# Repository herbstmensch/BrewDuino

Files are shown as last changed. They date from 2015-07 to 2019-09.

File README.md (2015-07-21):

# BrewDuino
BrewDuino ist eine einfache Brau-Steuerungs-Software für Hobbybrauer.

## Inhalt
- [Funktionen](#funktionen)
	- [Maischen](#maischen)
	- [Kochen](#kochen)
	- [Heizen](#heizen)
	- [Timer](#timer)
	- [Einstellungen (noch nicht implementiert)](#einstellungen)
- [Hardware](#hardware)
	- [Schaltplan](#schaltplan)
	- [Board](#board)
	- [Bauteile](#bauteile)
	- [Anschlüsse](#anschlüsse)
- [Bilder](#bilder)
	- [Board unbestückt](#board-unbestückt)
	- [Board bestückt](#boars-bestückt)

### Funktionen

#### Maischen
* Definition und Ausführung des Kompletten Maischeplans.
* Optische und akustische Warung bei Erreichen der Einmaischtemperatur
* Unterbrechung des Maischeplans, bis eingemaischt wurde
* Optische und akustische Warung bei Erreichen der Abmaischtemperatur

#### Kochen
* Freie Definition der Hopfengaben
* Sekundengenaue Messung der Kochzeit
* Optische und akustische Warung für Hopfengaben
* Optische und akustische Warung nach Ablauf der Kochzeit

#### Heizen
* Heizt auf eine eingegebene Temperatur
* Hält diese Temperatur dauerhaft

#### Timer
* Countdown einer eingegebenen Zeit
* Optische und akustische Warung bei Ablauf der Zeit

#### Einstellungen (noch nicht implementiert)
* Anpassung aller Betriebsparameter:
  * Ein-Ausschalt Temperaturoffset
  * Intervall der Temperaturmessungen
  * Ein- / Ausschalten der akustischen Warnungen
  * Ein- / Ausschalten der optischen Warnungen

### Hardware
* Prozessor: ATmega 328P, Arduino-Bootloader
* Display: Nokia 5110 Display (PCD8544)
* SainSmart Relaiskarte
* DS18B20 Temperatursensor
* Rotary Encoder mit Button
 
#### Schaltplan
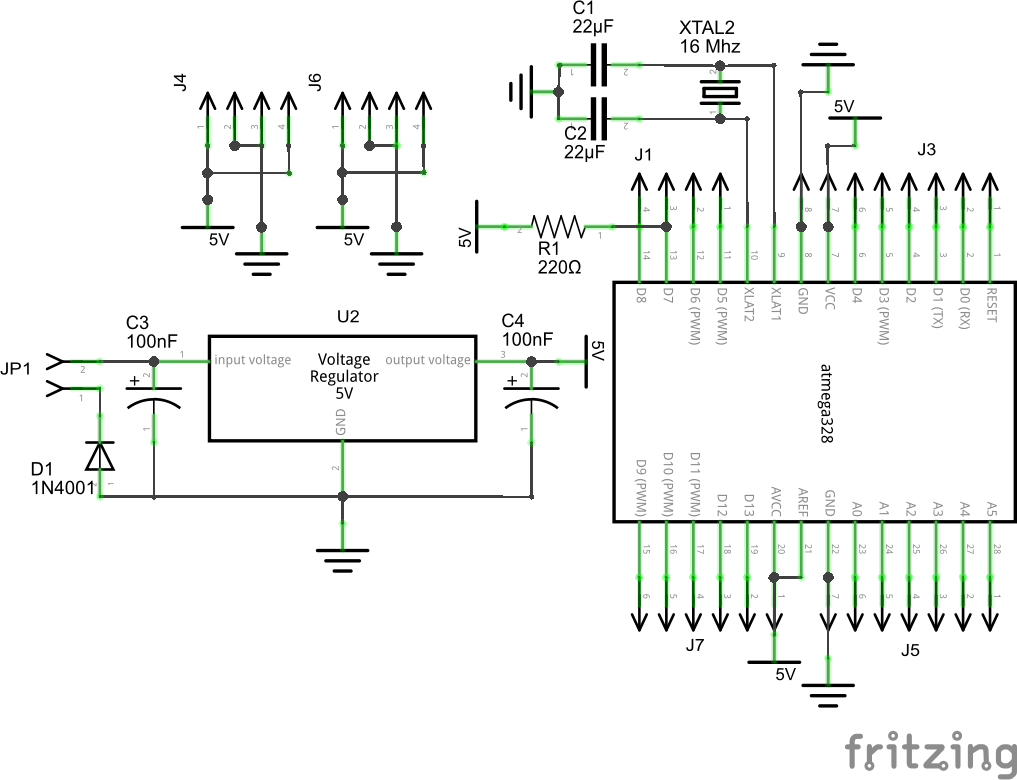
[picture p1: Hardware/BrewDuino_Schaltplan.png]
Schaltplan


#### Board
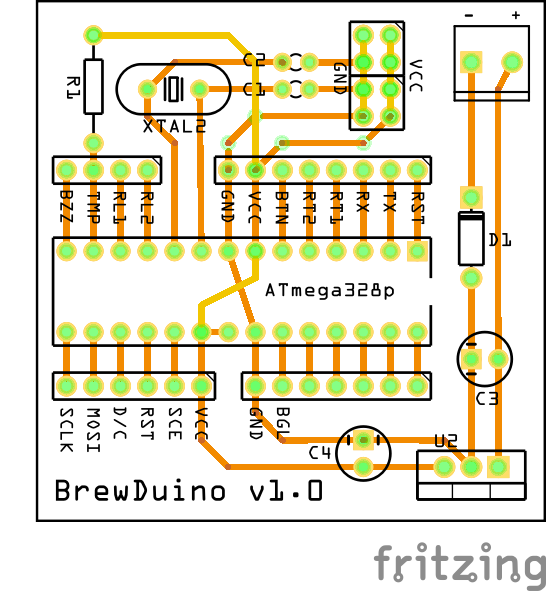
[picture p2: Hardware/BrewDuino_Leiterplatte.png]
PCB


#### Bauteile
Bezeichnung | Bauteil
------------ | -------------
C1 | Kondensator 22 uF
C2 | Kondensator 22 uF
C3 | Kondensator 100 nF
C4 | Kondensator 100 nF
U2 | Spannungsregulator
D1 | Diode
JX | PinHeader
XTAL2 | Quartz 16 Mhz
R1 | Wiederstand 220 Ohm

#### Anschlüsse
Bezeichung | Anschluß
-----------|---------
VCC  | Versorgungsspannung 5V
GND  | MAsse
SCE  | Nokia 5110 Display SCE
RST  | Nokia 5110 Display RST
D/C  | Nokia 5110 Display D/C
MOSI | Nokia 5110 Display MOSI
SCLK | Nokia 5110 Display SCLK
RST  | Reset (Arduino Reset)
TX   | Tranceive (Arduino Serial Programming)
RX   | Receive (Arduino Serial Programming)
RT1  | Rotary Encoder
RT2  | Rotary Encoder
BTN  | Button zur Eingabe
RL1  | Relais 1 (Kocher oder Heizplatte)
RL2  | Relais 2 (Rührwerk)
TMP  | Temperatursensor Data
BZZ  | Summer

### Bilder

#### Board unbestückt
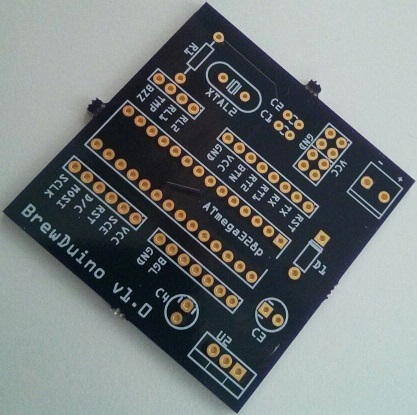
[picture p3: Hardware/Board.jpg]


#### Board bestückt
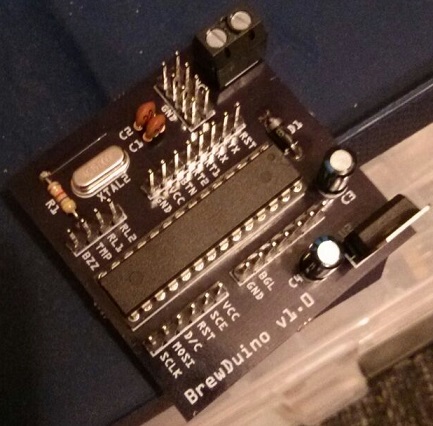
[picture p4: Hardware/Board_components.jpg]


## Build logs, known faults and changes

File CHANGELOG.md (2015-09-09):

# Changelog
## Version 1.1
Released: ---

Bug Fixes:
 - Fixed random program crashes due to String handling

## Version 1.0
Released: 2015-08-12

Changes: first release

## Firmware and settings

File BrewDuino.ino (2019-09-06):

#define CREATOR "rellit"
#define PROG_NAME "BrewDuino"
#define PROG_VERSION "v1.1"
#define COPYRIGHT "(c)2015 - 2019"
#define COPYRIGHT2 "Tim Haller"
#include <LCD5110_Basic.h>
#include <ClickEncoder.h>
#include <TimerOne.h>
#include "FiniteStateMachine.h"
#include <OneWire.h>
#include <DallasTemperature.h>

//Pins benennen
#define PIN_ROTARY_1 2
#define PIN_ROTARY_2 3
#define PIN_ROTARY_BUTTON 4
#define PIN_BG_LIGHT A0
#define PIN_STIRER 5
#define PIN_HEATER 6
#define PIN_THERMOMETER 7
#define PIN_BUZZER 8
#define PIN_LCD_SCLK 9
#define PIN_LCD_MOSI 10
#define PIN_LCD_DC 11
#define PIN_LCD_RST 12
#define PIN_LCD_SCE 13

#define NUMITEMS(arg) ((unsigned int) (sizeof (arg) / sizeof (arg [0])))

//Konfigurationsparameter festlegen
#define TEMP_OFFSET 1
#define MIN_TEMP -999
#define KOCH_TEMP 100
#define TMP_SMOOTH 5
#define MAX_LONG 2147483647L;
#define ENC_HALFSTEP
#define SERIAL J
#define DEBUG 0

//Fehler festlegen
#define ERROR_NO_THERMOMETER 1

int errors = 0, lastErrors = 0;

//Display einrichten
//Old LCD5110 lcd(8, 9, 10, 11, 12);
LCD5110 lcd(PIN_LCD_SCLK, PIN_LCD_MOSI, PIN_LCD_DC, PIN_LCD_RST, PIN_LCD_SCE);
extern uint8_t SmallFont[];
char lcdBuf[15] = {0, 0, 0, 0, 0, 0, 0, 0, 0, 0, 0, 0, 0, 0, 0}; //Buffer für Konkatenierte Display ausgaben

//Encoder einrichten;
ClickEncoder *encoder;
int16_t encoderValue;

//Temperatursensor DS1820 Initialisierung
OneWire oneWire(PIN_THERMOMETER);
DallasTemperature sensors(&oneWire);
DeviceAddress thermometer;

//Funktions-Prototypen
void initThermometer();
void enterMenu() ;
void leaveMenu();
void enterError();
void enterMaischen();
void leaveMaischen();
void enterKochen() ;
void leaveKochen();
void enterHeizen() ;
void leaveHeizen() ;
void enterTimer() ;
void menu() ;
void menuUp() ;
void menuDown();
void error() ;
void maischen() ;
void kochen() ;
void heizen();
void timer() ;
void readTemperature() ;
void setSollTemp(int t) ;
void checkHeatingStatus(bool force);
void turnOffHeating();
void turnOnHeating();
void turnOffStiring();
void turnOnStiring() ;
void addTemperature(boolean force);
void clrScr(bool clearFirst, bool clearLast);
void printRow(char* text, int pos, int row);
void timerIsr() ;
void forceFirstDisplay();
void alarm() ;
void doAlert() ;
void cancelAlarm() ;
bool buttonClicked();
void checkForErrors();
void doHeizen();
void enterKochzeit() ;
void enterAnzahlHopfengaben() ;
void defineHopfengaben();
void enterDoKochen();
void doKochen() ;
void prepareReachKochTemp();
void reachKochTemp() ;
void prepareKochDauer();
void waitKochDauer() ;
void alertHopfengabe();
void enterEinmaischTemp() ;
void enterAnzahlRasten() ;
void defineRast();
void enterAbmaischTemp() ;
void prepareReachEinmaischTemp();
void reachEinmaischTemp();
void einmaischen();
void reachRastTemp() ;
void prepareRastDauer() ;
void waitRastDauer() ;
void reachAbmaischTemp();
void doTimer();
void prepareDoTimer();
void enterTimerTime();

//Main FSM und States definieren
State stateMenu = State(enterMenu, menu, leaveMenu);
State stateError = State(enterError, error, NULL);
State stateMaischen = State(enterMaischen, maischen, leaveMaischen);
State stateKochen = State(enterKochen, kochen, leaveKochen);
State stateHeizen = State(enterHeizen, heizen, leaveHeizen);
State stateTimer = State(enterTimer, timer, NULL);
//State stateSettings = State(enterSettings, settings, NULL);
FSM fsmMain = FSM(stateMenu);

//Maischen FSM und States definieren
State stateEnterEinmaischTemp = State(forceFirstDisplay, enterEinmaischTemp, NULL);
State stateEnterAnzahlRasten = State(forceFirstDisplay, enterAnzahlRasten, NULL);
State stateDefineRast = State(forceFirstDisplay, defineRast, NULL);
State stateEnterAbmaischTemp = State(forceFirstDisplay, enterAbmaischTemp, NULL);
State stateReachEinmaischTemp = State(prepareReachEinmaischTemp, reachEinmaischTemp, NULL);
State stateEinmaischen = State(einmaischen);
State stateReachRastTemp = State(reachRastTemp);
State stateWaitRastDauer = State(prepareRastDauer, waitRastDauer, NULL);
State stateReachAbmaischTemp = State(NULL, reachAbmaischTemp, NULL);
FSM fsmMaischen = FSM(stateEnterEinmaischTemp);

//Kochen FSM und States definieren
State stateEnterKochzeit = State(forceFirstDisplay, enterKochzeit, NULL);
State stateEnterAnzahlHopfengaben = State(forceFirstDisplay, enterAnzahlHopfengaben, NULL);
State stateDefineHopfengaben = State(forceFirstDisplay, defineHopfengaben, NULL);
State stateDoKochen = State(enterDoKochen, doKochen, NULL);
FSM fsmKochen = FSM(stateEnterKochzeit);

//Timer FSM und States definieren
State stateEnterTimerTime = State(forceFirstDisplay, enterTimerTime, NULL);
State stateDoTimer = State(prepareDoTimer, doTimer, NULL);
FSM fsmTimer = FSM(stateEnterTimerTime);

//Variablen initialisieren

int selectedMenuEntry = 0, menuOffset = 0;
//char* menuEntrys[] = {"Maischen","Kochen","Heizen","Timer","Einstell."};
char* menuEntrys[] = {"Maischen", "Kochen", "Heizen", "Timer"};
float lastTemps[TMP_SMOOTH] = {0, 0, 0, 0, 0};
float tempTotal = 0;
int temp, lastTemp, sollTemp, lastHeatCheckTemp, tmpIndex = 0;

unsigned long lastRest = -1;
unsigned long dauer = 0;
unsigned long storedSystemMillis = 0;
unsigned long lastTempMillis;
unsigned long alertMillis = 0;

bool first = false;
bool isHeating, isStiring = false;

void setup()   {
  //LCD Setup
  lcd.InitLCD();
  lcd.clrScr();
  lcd.setFont(SmallFont);
  printRow(CREATOR, LEFT, 0);
  printRow(PROG_NAME" "PROG_VERSION, LEFT, 16);
  printRow(COPYRIGHT, LEFT, 32);
  printRow(COPYRIGHT2, RIGHT, 40);
  Serial.begin(9600);
  Serial.print("Test");


  pinMode(PIN_BG_LIGHT, OUTPUT);
  pinMode(PIN_HEATER, OUTPUT);
  pinMode(PIN_STIRER, OUTPUT);
  digitalWrite(PIN_BG_LIGHT, LOW);
  digitalWrite(PIN_HEATER, HIGH);
  digitalWrite(PIN_STIRER, HIGH);

  isStiring = false;

  //Encoder und Interrupt Setup
  encoder = new ClickEncoder(PIN_ROTARY_1, PIN_ROTARY_2, PIN_ROTARY_BUTTON, 4);
  encoder->setAccelerationEnabled(false);
  Timer1.initialize(1000);
  Timer1.attachInterrupt(timerIsr);

  //Temperaturen und Heizung initialisieren
  setSollTemp(MIN_TEMP);
  isHeating = false;

  initThermometer();

  checkForErrors();
  delay(2000);
  if (errors > 0) {
    fsmMain.immediateTransitionTo(stateError);
    alarm();
  } else {
    fsmMain.immediateTransitionTo(stateMenu);
  }
}

void loop() {
  fsmMain.update();
  ClickEncoder::Button b = encoder->getButton();
  if (b != ClickEncoder::Open) {
    if ( b == ClickEncoder::Held ) {
      fsmMain.transitionTo(stateMenu);
    }
  }

  readTemperature();
  checkHeatingStatus(false);
  addTemperature(false);

  if (alertMillis != 0)
    doAlert();
}

void initThermometer() {
  sensors.begin();
  sensors.getAddress(thermometer, 0);
  // set the resolution to 9 bit (Each Dallas/Maxim device is capable of several different resolutions)
  sensors.setResolution(thermometer, 9);
  //Init Temp array
  for (int i = 0; i < TMP_SMOOTH; i++) {
    sensors.setWaitForConversion(true);
    sensors.requestTemperatures();
    //Letzte Temperatur dieser Position aus Summe nehmen
    tempTotal -= lastTemps[tmpIndex];
    //Neue Temperatur dieser Position schreiben
    lastTemps[tmpIndex] = sensors.getTempC(thermometer);
    //Neue Temperatur dieser Position zur Summe hinzunehmen und Position erhöhen
    tempTotal += lastTemps[tmpIndex++];

    //Durchschnitt errechnen
    temp = tempTotal / TMP_SMOOTH;
  }

  tmpIndex = 0;
  sensors.setWaitForConversion(false);
  sensors.requestTemperatures();
}

void enterMenu() {
  encoder->setAccelerationEnabled(false);
  //selectedMenuEntry = 0;
  //menuOffset = 0;
  setSollTemp(MIN_TEMP);
  checkHeatingStatus(true);
  clrScr(true, false);
  printRow(PROG_NAME" "PROG_VERSION, CENTER, 0);
  forceFirstDisplay();
}

void leaveMenu() {
  encoder->setAccelerationEnabled(true);
}

void enterError() {
  setSollTemp(MIN_TEMP);
  checkHeatingStatus(true);
  clrScr(true, true);
  printRow("--Fehler--", CENTER, 0);
  forceFirstDisplay();
}

void enterMaischen() {
  encoder->setAccelerationEnabled(true);
  fsmMaischen.immediateTransitionTo(stateEnterEinmaischTemp);
  clrScr(true, false);
  printRow("--Maischen--", CENTER, 0);
}

void leaveMaischen() {
  setSollTemp(MIN_TEMP);
}

void enterKochen() {
  encoder->setAccelerationEnabled(true);
  setSollTemp(KOCH_TEMP);
  checkHeatingStatus(true);
  fsmKochen.immediateTransitionTo(stateEnterKochzeit);
  clrScr(true, false);
  printRow("--Kochen--", CENTER, 0);
}

void leaveKochen() {
  setSollTemp(MIN_TEMP);
}

void enterHeizen() {
  encoder->setAccelerationEnabled(true);
  setSollTemp(temp);
  clrScr(true, false);
  printRow("--Heizen--", CENTER, 0);
  forceFirstDisplay();
}

void leaveHeizen() {
  setSollTemp(MIN_TEMP);
}

void enterTimer() {
  encoder->setAccelerationEnabled(true);
  fsmTimer.immediateTransitionTo(stateEnterTimerTime);
  clrScr(true, false);
  printRow("--Timer--", CENTER, 0);
}

/*void enterSettings(){
  fsmSettings.immediateTransitionTo();
  }*/

void menu() {
  encoderValue = encoder->getValue();

  if (encoderValue != 0 || first) {
    first = false;
    if (encoderValue > 0)
      for (int i = 0; i < encoderValue; i++)
        menuUp();
    if (encoderValue < 0)
      for (int i = encoderValue; i < 0; i++)
        menuDown();

    clrScr(false, false);
    if (selectedMenuEntry == 0 + menuOffset)
      printRow("=>", 10, 16);
    lcd.print(menuEntrys[0 + menuOffset], 25, 16);
    if (selectedMenuEntry == 1 + menuOffset)
      printRow("=>", 10, 24);
    lcd.print(menuEntrys[1 + menuOffset], 25, 24);
  }

  if (buttonClicked()) {
    if (selectedMenuEntry == 0)
      fsmMain.transitionTo(stateMaischen);
    if (selectedMenuEntry == 1)
      fsmMain.transitionTo(stateKochen);
    if (selectedMenuEntry == 2)
      fsmMain.transitionTo(stateHeizen);
    if (selectedMenuEntry == 3)
      fsmMain.transitionTo(stateTimer);
    //if(selectedMenuEntry == 4)
    //fsmMain.transitionTo(stateSettings);
    //alarm();
  }
}

void menuUp() {
  selectedMenuEntry -= 1;
  if (selectedMenuEntry < 0)
    selectedMenuEntry = 0;
  if (selectedMenuEntry < menuOffset)
    menuOffset--;
}

void menuDown() {
  selectedMenuEntry += 1;
  if (selectedMenuEntry > NUMITEMS(menuEntrys) - 1)
    selectedMenuEntry = NUMITEMS(menuEntrys) - 1;
  if (selectedMenuEntry > menuOffset + 1)
    menuOffset += 1;
}

void error() {
  if (lastErrors != errors || first) {

    lastErrors = errors;

    if (errors >= ERROR_NO_THERMOMETER) {
      errors -= ERROR_NO_THERMOMETER;
      lcd.print("Kein Therm.", 0, 16);
    }

  }
}

void maischen() {
  fsmMaischen.update();
}

void kochen() {
  fsmKochen.update();
}

void heizen() {
  doHeizen();
}

void timer() {
  fsmTimer.update();
}
/*void settings(){
  fsmSettings.update();
  }*/

void readTemperature() {

  //Gelesen wir nur alle 2,5 sec.
  if (millis() - lastTempMillis > 2500 && sensors.isConversionAvailable(0)) {
    lastTempMillis = millis();

    //Letzte Temperatur dieser Position aus Summe nehmen
    tempTotal -= lastTemps[tmpIndex];
    //Neue Temperatur dieser Position schreiben
    lastTemps[tmpIndex] = sensors.getTempC(thermometer);
    //Neue Temperatur dieser Position zur Summe hinzunehmen und Position erhöhen
    tempTotal += lastTemps[tmpIndex++];

    //Durchschnitt errechnen
    temp = tempTotal / TMP_SMOOTH;

    //Ggf. Position korrigieren
    if (tmpIndex >= TMP_SMOOTH)
      tmpIndex = 0;

    //Neue Temperatur anfordern
    sensors.requestTemperatures();
  }
}

void setSollTemp(int t) {
  sollTemp = t;
  checkHeatingStatus(true);
}

void checkHeatingStatus(bool force) {
  if (temp != lastHeatCheckTemp || force) {
    lastHeatCheckTemp = temp;
    //Ein oder ausschalten des Heizelementes.
    //Evtl. schaltfrequent sicherstellen

    //-127 heißt kein Thermometer
    if (temp != -127) {
      if (isHeating) {
        if (temp >= sollTemp + TEMP_OFFSET)
          turnOffHeating();
      } else {
        if (temp <= sollTemp - TEMP_OFFSET)
          turnOnHeating();
      }
    }
  }
}

void turnOffHeating() {
  //Toggle Relais
  isHeating = false;
  digitalWrite(PIN_HEATER, HIGH);
  addTemperature(true);
}

void turnOnHeating() {
  //Toggle Relais
  isHeating = true;
  digitalWrite(PIN_HEATER, LOW);
  addTemperature(true);
}

void turnOffStiring() {
  //Toggle Relais
  isStiring = false;
  digitalWrite(PIN_STIRER, HIGH);
}

void turnOnStiring() {
  //Toggle Relais
  isStiring = true;
  digitalWrite(PIN_STIRER, LOW);
}

void addTemperature(boolean force) {
  //Wenn die aktuelle Temperatur nciht der angezeigten entspricht, aktualisieren.
  if (temp != lastTemp || force) {
    lastTemp = temp;
    lcd.clrRow(5);
    snprintf(lcdBuf, sizeof(lcdBuf), "%sist: %i~ C\0", isHeating ? "H " : "", temp);
    printRow(lcdBuf, RIGHT, 40);
  }
}

void clrScr(bool clearFirst, bool clearLast) {
  if (clearFirst && clearLast) {
    lcd.clrScr();
    return;
  }
  if (clearFirst) {
    lcd.clrRow(0);
  }
  lcd.clrRow(1);
  lcd.clrRow(2);
  lcd.clrRow(3);
  lcd.clrRow(4);
  if (clearLast) {
    lcd.clrRow(5);
  }
}

void printRow(char* text, int pos, int row) {
  if (row > 5) //Received pixel instead of line
    row = row / 8;

  if (row > 5) return; //We have only 6 lines.

  lcd.clrRow(row);
  lcd.print(text, pos, row * 8);
}

void timerIsr() {
  encoder->service();
}

void forceFirstDisplay() {
  first = true;
}

void alarm() {
  alertMillis = millis();
}

void doAlert() {
  unsigned long dur = millis() - alertMillis;

  if ((dur / 250) % 4 == 0) {
    tone(PIN_BUZZER, 800, 250);
  } else if ((dur / 250) % 2 == 0) {
    tone(PIN_BUZZER, 970, 250);
  } else {
    noTone(PIN_BUZZER);
  }
  if ((dur / 500) % 2 == 0) {
    digitalWrite(PIN_BG_LIGHT, LOW);
  } else {
    digitalWrite(PIN_BG_LIGHT, HIGH);
  }

  //Nach spät. 10 sec. den Alarm Abbrechen
  if (dur >= 10000) {
    cancelAlarm();
  }
}

void cancelAlarm() {
  alertMillis = 0;
  noTone(PIN_BUZZER);
  digitalWrite(PIN_BG_LIGHT, LOW);
}

bool buttonClicked() {
  ClickEncoder::Button b = encoder->getButton();
  if (b != ClickEncoder::Open) {
    if (b == ClickEncoder::Clicked )
      return true;
  }
  return false;
}

void checkForErrors() {
  if (-128 < temp && -126 > temp) {
    //Kein Thermometer
    errors += ERROR_NO_THERMOMETER;
  }
}

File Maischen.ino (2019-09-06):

int einmaischTemp = 48;
int abmaischTemp = 78;
int anzahlRasten = 3;
int rastTemp[10] = {0,0,0,0,0,0,0,0,0,0};
int rastDauer[10] = {0,0,0,0,0,0,0,0,0,0};

int aktuelleRast = 0;
int subState = 0;

void enterEinmaischTemp() {
  
  encoderValue = encoder->getValue();
  if(encoderValue != 0 || first){
    first = false;
    einmaischTemp += encoderValue;  
    if(einmaischTemp < 0)
      einmaischTemp = 0;
 
    clrScr(false,false);
    lcd.print("Einmaisch-.",0,16);
    lcd.print("Temp.: ",0,24);
    lcd.invertText(true);
    lcd.printNumI(int(einmaischTemp),49,24);
    lcd.invertText(false);
    lcd.print("~ C",70,24);
  }
  
  if(buttonClicked()){
    fsmMaischen.immediateTransitionTo(stateEnterAnzahlRasten);
  } 
  
}


void enterAnzahlRasten() {
  encoderValue = encoder->getValue();
  if(encoderValue != 0 || first){
    first = false;
    anzahlRasten += encoderValue;
    if(anzahlRasten < 0)
      anzahlRasten = 0;
    if(anzahlRasten > 10)
      anzahlRasten = 10;
    
    clrScr(false,false);
    lcd.print("Anzahl Rasten",0,16);
    lcd.invertText(true);
    lcd.printNumI(int(anzahlRasten),15,24);
    lcd.invertText(false);
  }
  
  if(buttonClicked()){
    if(anzahlRasten > 0){
      subState = 0;
      aktuelleRast = 0;
      rastTemp[aktuelleRast] = einmaischTemp;
      rastDauer[aktuelleRast] = 30;
      
      fsmMaischen.immediateTransitionTo(stateDefineRast);
    }
    else
      fsmMaischen.immediateTransitionTo(stateEnterAbmaischTemp);
  } 
}



void defineRast() {
  encoderValue = encoder->getValue();
  if(encoderValue != 0 || first){
    first = false;
    if(subState == 0 ){
      rastTemp[aktuelleRast] += encoderValue;
      if(rastTemp[aktuelleRast] < 0)
        rastTemp[aktuelleRast] = 0;
    } else {
      rastDauer[aktuelleRast] += encoderValue;
      if(rastDauer[aktuelleRast] < 0)
        rastDauer[aktuelleRast] = 0;
    }
      
    clrScr(false,false);
    lcd.printNumI(int(aktuelleRast+1),8,12);
    lcd.print(". Rast",15+(aktuelleRast>9?7:0),8);
    lcd.print("Temp:",15,20);
    lcd.invertText(subState==0);
    lcd.printNumI(int(rastTemp[aktuelleRast]),57,16);
    lcd.invertText(false);
    lcd.print("Dauer:",15,24);
    lcd.invertText(subState==1);
    lcd.printNumI(int(rastDauer[aktuelleRast]),57,24);
    lcd.invertText(false);
  }
  
  if(buttonClicked()){
    if(subState == 0 ){
      subState = 1;
      first = true;
    } else {
      subState = 0;
      aktuelleRast += 1;
      first = true;
      if(aktuelleRast >= anzahlRasten){
        fsmMaischen.immediateTransitionTo(stateEnterAbmaischTemp);
      } else {
        rastTemp[aktuelleRast] = rastTemp[aktuelleRast-1];
        rastDauer[aktuelleRast] = 30;
      }
      }
  } 
}

void enterAbmaischTemp() {
  encoderValue = encoder->getValue();
  if(encoderValue != 0 || first){
    first = false;
    abmaischTemp += encoderValue;  
    if(abmaischTemp < 0)
      abmaischTemp = 0;
    
    clrScr(false,false);
    lcd.print("Abmaisch-",0,16);
    lcd.print("Temp: ",0,24);
    lcd.invertText(true);
    lcd.printNumI(int(abmaischTemp),49,24);
    lcd.invertText(false);
    lcd.print("~ C",70,24);
  }
  
  if(buttonClicked()){
    fsmMaischen.immediateTransitionTo(stateReachEinmaischTemp);
  } 
}

void prepareReachEinmaischTemp() {
  setSollTemp(MIN_TEMP);
}

void reachEinmaischTemp() {
  if(sollTemp == MIN_TEMP){
    setSollTemp(einmaischTemp);
    turnOnStiring();
    
    clrScr(false,false);
    
    lcd.print("Warte auf", CENTER, 8);
    lcd.print("Einmaischtemp", CENTER, 16);
    snprintf(lcdBuf,sizeof(lcdBuf),"%i~C\0",einmaischTemp);
    lcd.print(lcdBuf, CENTER, 24);
  }
  
  #if DEBUG == 1
  temp = einmaischTemp+1;
  #endif
  
  if(temp >= einmaischTemp){
    setSollTemp(MIN_TEMP);
    alarm();
    fsmMaischen.immediateTransitionTo(stateEinmaischen);
  }
  
}

void einmaischen() {
  if(sollTemp==MIN_TEMP){
    //Temperatur ändern um Display reload zu verhindern
    //Wert sollte so klein sein, dass nicht geheizt wird.
    setSollTemp(MIN_TEMP+1);
    
    clrScr(false,false);
    
    lcd.print("Einmaischen", CENTER, 8);
    lcd.print("Weiter mit", CENTER, 16);
    lcd.print("Klick", CENTER, 24);
  }
  
  if(buttonClicked()){
    setSollTemp(MIN_TEMP);
    aktuelleRast = 0;
    cancelAlarm();
    if(anzahlRasten > 0){
      fsmMaischen.immediateTransitionTo(stateReachRastTemp);
    }
    else 
      fsmMaischen.immediateTransitionTo(stateReachAbmaischTemp);
  } 
}

void reachRastTemp() {
  if(sollTemp==MIN_TEMP){
     setSollTemp(rastTemp[aktuelleRast]);
    clrScr(false,false);
    
    lcd.print("Warte auf", CENTER, 8);
    snprintf(lcdBuf,sizeof(lcdBuf),"%i. Rast Temp.\0",aktuelleRast+1);
    lcd.print(lcdBuf, CENTER, 16);
    snprintf(lcdBuf,sizeof(lcdBuf),"%i~ C\0",rastTemp[aktuelleRast]);
    lcd.print(lcdBuf, CENTER, 24);
  }

  #if DEBUG == 1
  temp = rastTemp[aktuelleRast]+1;
  #endif
  
  if(temp >= rastTemp[aktuelleRast]){
    fsmMaischen.immediateTransitionTo(stateWaitRastDauer);
  }
}

void prepareRastDauer() {
  lastRest = MAX_LONG;
  storedSystemMillis = millis();
  dauer = rastDauer[aktuelleRast]*60*1000L;
}

void waitRastDauer() {
  long rest = dauer - (millis()-storedSystemMillis);
  
  //Anzeige nur ändern, wenn eine Sekunde vergangen ist.
  if(lastRest-rest >= 500){
    lastRest = rest;
    int std = ((rest/1000) / 60) / 60;
    int min = ((rest/1000) / 60) % 60;
    int sec = (rest/1000) % 60;
  
    clrScr(false,false);

    snprintf(lcdBuf,sizeof(lcdBuf),"%i. Rast:\0",aktuelleRast+1);
    lcd.print(lcdBuf, CENTER, 8);
    
    snprintf(lcdBuf,sizeof(lcdBuf),"%i~ C / %imin\0",rastTemp[aktuelleRast],rastDauer[aktuelleRast]);
    lcd.print(lcdBuf, CENTER, 16);
    
    if(std > 0){
     snprintf(lcdBuf, sizeof(lcdBuf), (rest/500)%2==0?"noch %.2i:%.2i:%.2i\0":"noch %.2i %.2i %.2i\0",std,min,sec);
    } else {
      snprintf(lcdBuf, sizeof(lcdBuf), (rest/500)%2==0?"noch %02d:%02d\0":"noch %02d %02d\0",min,sec);
    }
    lcd.print(lcdBuf, CENTER, 24);
  }
  
  if(rest <= 0){
    setSollTemp(MIN_TEMP);
    if(anzahlRasten > aktuelleRast+1){
      aktuelleRast += 1;
      lastRest = MAX_LONG;
      fsmMaischen.immediateTransitionTo(stateReachRastTemp);
    } else {
      fsmMaischen.immediateTransitionTo(stateReachAbmaischTemp);
    }
  }
}

void reachAbmaischTemp() {
  if(sollTemp == MIN_TEMP){
    setSollTemp(abmaischTemp);
    
    clrScr(false,false);
    
    lcd.print("Warte auf", CENTER, 8);
    lcd.print("Abmaischtemp.", CENTER, 16);
    snprintf(lcdBuf,sizeof(lcdBuf),"%i~ C\0",abmaischTemp);
    lcd.print(lcdBuf, CENTER, 24);
  }
  if(temp >= abmaischTemp){
    alarm();
    turnOffStiring();
    fsmMain.immediateTransitionTo(stateMenu);
  }
  
}

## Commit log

2015-05-29 Maisch-Einstellungen und das Maischen bis Erreichen der Ersten Rast Temperatur implementiert
2015-06-02 Store Old Encoder
2015-06-03 Update Kochen.ino
    Timer ":" animiert
2015-06-04 Einmaisch State hinzugefügt, Bug bei Rastendefinition behoben
    [BrewDuino.ino, Kochen.ino, Maischen.ino]
2015-06-10 Finished Timer, Heizen and cleaned up code
2015-06-11 Quellcode-Fehler behoben. Test der Umbauten steht aus.
    [BrewDuino.ino, Timer.ino]
2015-07-08 Hardware Layout hinzugefügt
    [BrewDuino.fzz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]
2015-07-08 Schaltplan und PCB Layout exportiert
    [BrewDuino.fzz]
2015-07-10 Layout optimiert
    [BrewDuino.fzz]
2015-07-21 Bilder vom Board hinzugefügt
2015-08-12 Temperatur asynchron lesen. Das macht den ablauf flüssiger. Alarm ton "verschönert".
2016-05-10 Corrected reading ClickButton leading to resets
    [BrewDuino.ino]
2019-09-06 Fehler beim Kochen behoben
    [BrewDuino.ino, Kochen.ino, Maischen.ino]
